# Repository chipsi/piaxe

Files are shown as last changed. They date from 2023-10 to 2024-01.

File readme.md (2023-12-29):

This Raspberry Pi mining HAT is based on the [BitAxe Ultra 1.3](https://github.com/skot/bitaxe
) (with BM1366) design.

Update: Miner is running stable 🥳



Changes to BitAxe Ultra
=======================

- powered by 12V and
- added TVS diode and fuses
- revised buck switching regulator circuit
- revised heatsink
- removed like DAC (only fixed 1.2V on PiAxe), current measurement, fan PWM controller, additional testpoints
- smallest components have 0805 size for easier manual assembly
- LM75 compatible temperature sensor under the heatsink

Installation
=============

- add to `/boot/config.txt`:
```
dtoverlay=pwm
```

- enable `serial` and `I2C` via `raspi-config`

If you want to use Influx and Grafana you need docker too:

```bash
$ curl -sSL https://get.docker.com | sh
```

Python:
```bash
# install pip3
$ sudo apt install python3-pip

# install libraries
$ for lib in pyserial rpi_hardware_pwm smbus influxdb-client pytz; do pip3 install $lib; done

# install i2c-tools
$ sudo apt install i2c-tools
```

Mining Client
=============



Stratum Mining Client:<br>
https://github.com/shufps/piaxe-miner

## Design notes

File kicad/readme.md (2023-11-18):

Original Repository: https://github.com/skot/bitaxe

This is a variant (Bitaxe ultra 1.3 with BM1366) for Raspberry Pi.

Please don't use it for production yet, the previous version had some issues and the 1.2 version is not yet tested.



Differences:

- powered by 12V and
- added some protection like TVS diode and fuses
- revised buck switching regulator circuit
- revised heatsink
- removed every additional features like DAC, current- and temperature measurement, temperature controlled fan PWM controller, additional testpoints
- replaced level shifter IC with smaller one-channel SC70-5 types
- smallest components have 0805 size for easier manual assembly

Installation:

- add to `/boot/config.txt`:
```
dtoverlay=pwm
```

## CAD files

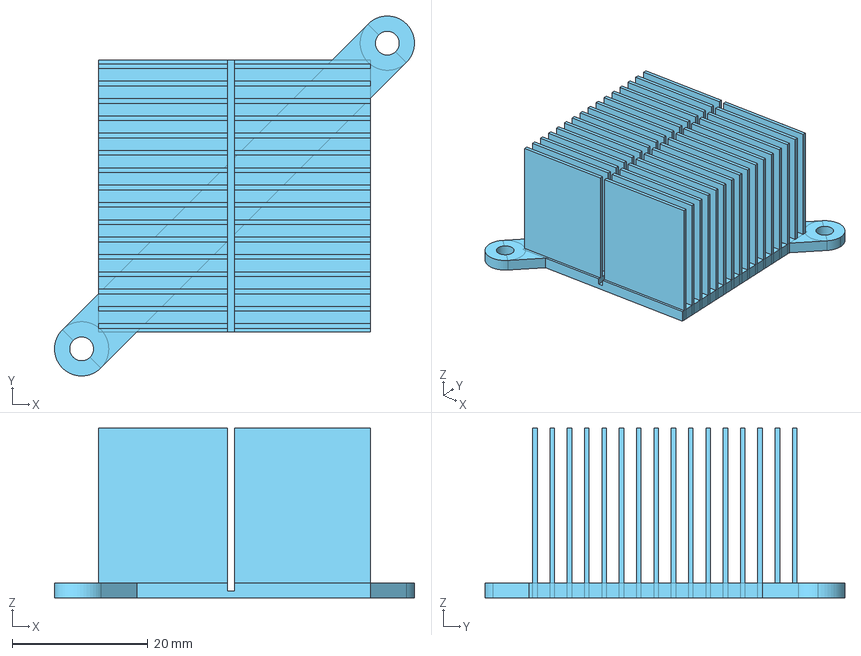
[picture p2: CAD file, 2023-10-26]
3d/heatsink-40x40-2.step
53.0 x 53.0 x 25.0 mm

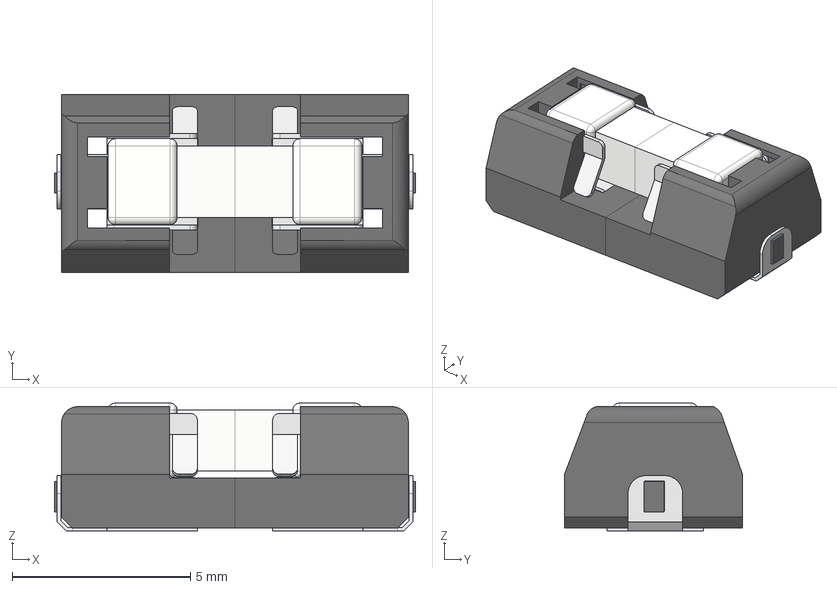
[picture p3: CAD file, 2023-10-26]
3d/Littelfuse 0154.500DRT without value_black v2.step
10.1 x 5.00 x 3.59 mm
Komponente1
Komponente2
Komponente3
Komponente4

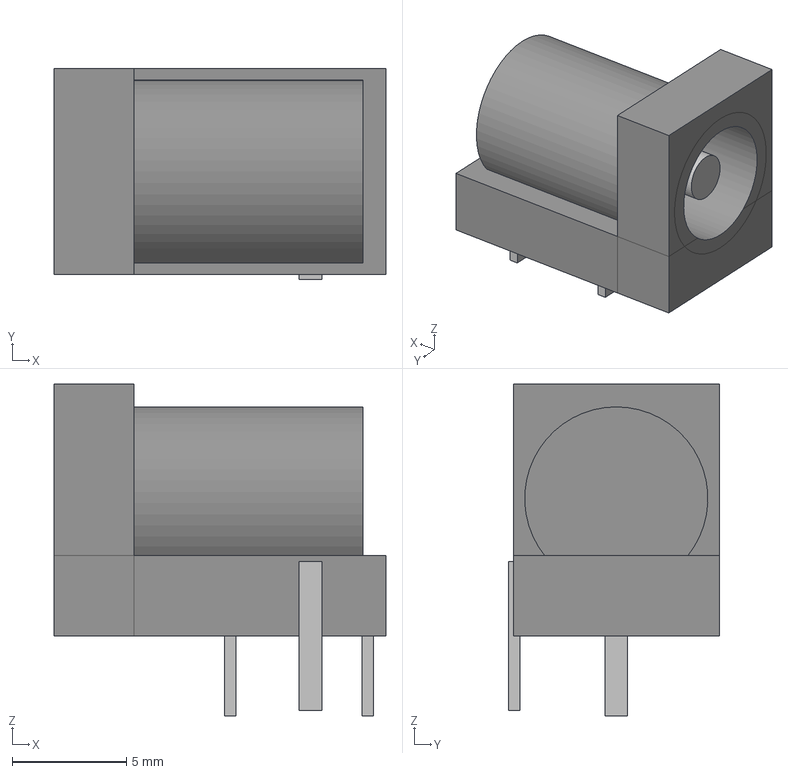
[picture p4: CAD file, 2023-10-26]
3d/barrel-jack.step
14.5 x 9.20 x 14.5 mm

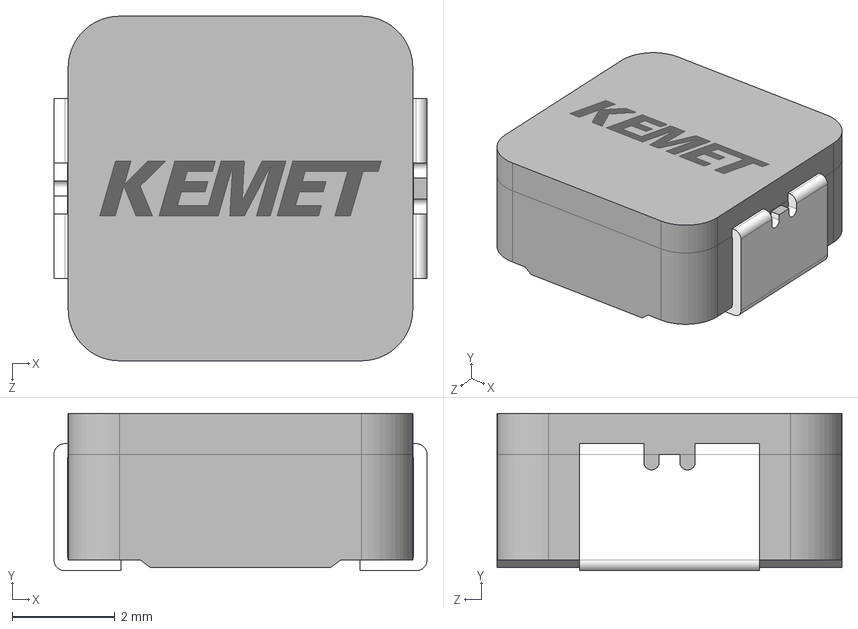
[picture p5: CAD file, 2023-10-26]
3d/MPXV1D0630LR33.step
7.25 x 3.06 x 6.70 mm

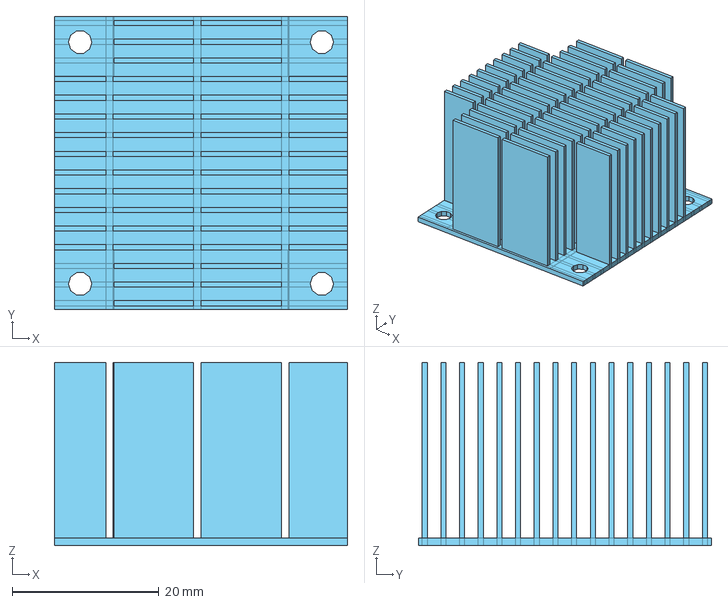
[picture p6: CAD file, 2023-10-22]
3d/heatsink-40x40.step
40.0 x 40.0 x 25.0 mm

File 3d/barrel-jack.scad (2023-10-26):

$fn=50;

color("#404040") difference() {
    union() {
        translate([0, 0, 6]) rotate([0,90,0]) cylinder(d=8, h=13.5);
        translate([0, -4.5, 0]) cube([3.5, 9, 11]);
        translate([0, -4.5, 0]) cube([14.5, 9, 3.5]);
    }
    translate([-1, 0, 6]) rotate([0,90,0]) cylinder(d=6.4, h=14);
}

color("gray") translate([1, 0, 6]) rotate([0,90,0]) cylinder(d=2.5, h=12);

color("gray") {
//    translate([7.7, 0, -3.5]) cylinder(d=1, h=3.5);
//    translate([7.7 + 6, 0, -3.5]) cylinder(d=1, h=3.5);
//    translate([7.7 + 3, -4.7, -3.5]) cylinder(d=1, h=6.5);

    translate([7.7, 0, -3.5/2]) cube([0.5, 1, 3.5], center=true);
    translate([7.7 + 6, 0, -3.5/2]) cube([0.5, 1, 3.5], center=true);
    translate([7.7 + 3, -4.7, -6.5/2]) cube([1, 0.5, 6.5]);
    
    
    
}

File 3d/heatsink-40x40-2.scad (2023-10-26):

$fn=100;
a=8.1;
h=3.5;
color("#31aee1") difference() {
    union() {
        cube([40, 40, 2.2]);

        for (i=[0: 15]) {
            translate([0, 0.5+i*2.55, 0]) cube([40, 0.7, 25]);
        }
        translate([20, 20, 1.1]) rotate([0, 0, 45]) cube([71.6-8, 8, 2.2], center=true);
        translate([-2.5, -2.5, 1.1]) cylinder(d=8, h=2.2, center=true);
        translate([2.5+40, 2.5+40, 1.1]) cylinder(d=8, h=2.2, center=true);
    }
    translate([20-1, 0, 1]) cube([1, 40, 25]);
    translate([-2.5, -2.5, 1.0]) cylinder(d=3.5, h=2.5, center=true);
    translate([2.5+40, 2.5+40, 1.0]) cylinder(d=3.5, h=2.5, center=true);
}

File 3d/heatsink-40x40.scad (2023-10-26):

$fn=10;
a=8.1;
h=3.5;
color("#31aee1") difference() {
    union() {
        cube([40, 40, 1]);

        for (i=[0: 15]) {
            translate([0, 0.5+i*2.55, 0]) cube([40, 0.7, 25]);
        }
    }
    for (i=[0:3]) {
        tx = (i % 2) == 0 ? 0 : (40-a);
        ty = floor(i / 2) != 0 ? 0 : (40-a);
        translate([tx, ty, 1]) cube([a, a, 25]);
    }
    for (i=[0:3]) {
        tx = (i % 2) == 0 ? h : (40-h);
        ty = floor(i / 2) != 0 ? h : (40-h);
        translate([tx, ty, -1]) cylinder(d=3.2, h=10);
    }
    translate([20-1, 0, 1]) cube([1, 40, 25]);
    translate([20-1+12, 0, 1]) cube([1, 40, 25]);
    translate([20-1-12, 0, 1]) cube([1, 40, 25]);
}

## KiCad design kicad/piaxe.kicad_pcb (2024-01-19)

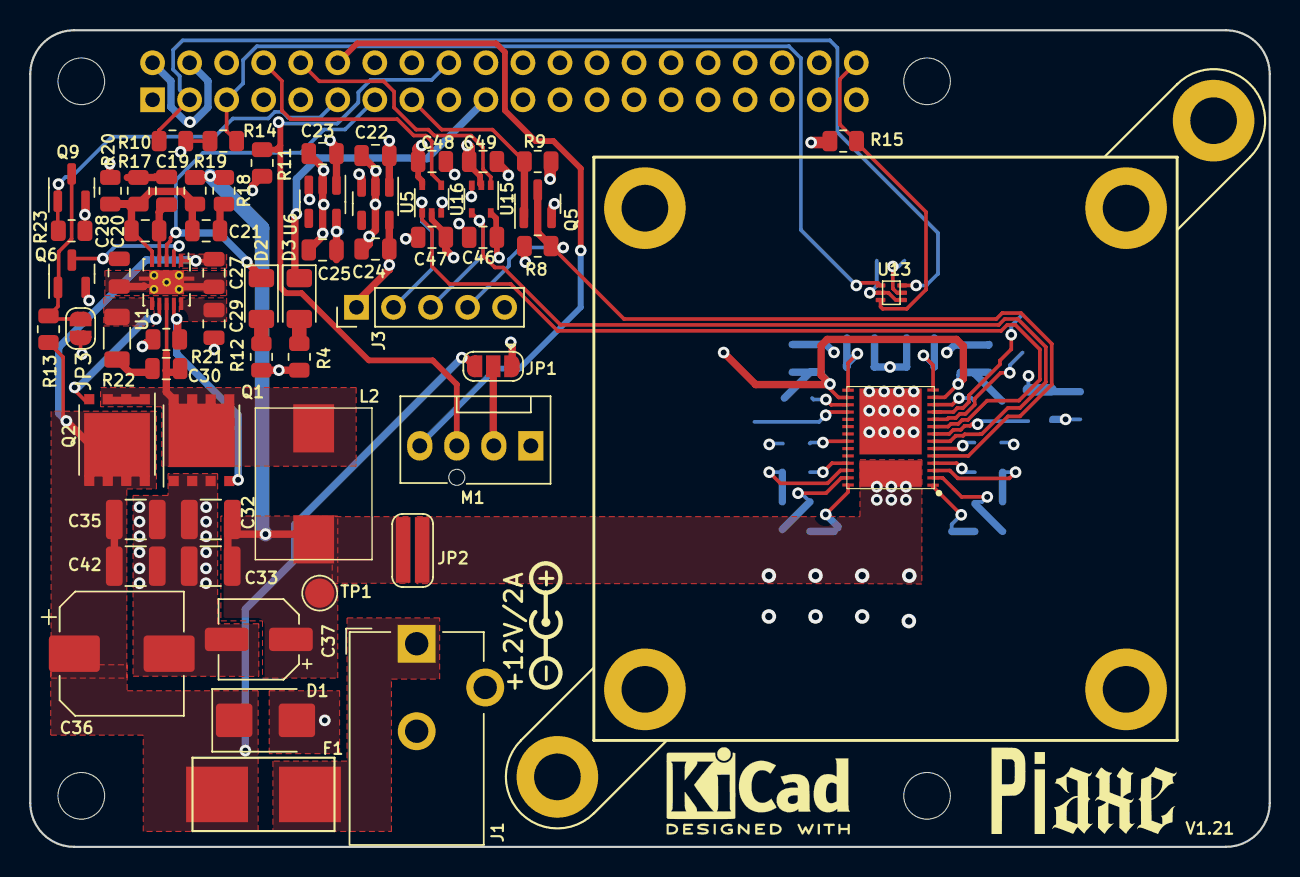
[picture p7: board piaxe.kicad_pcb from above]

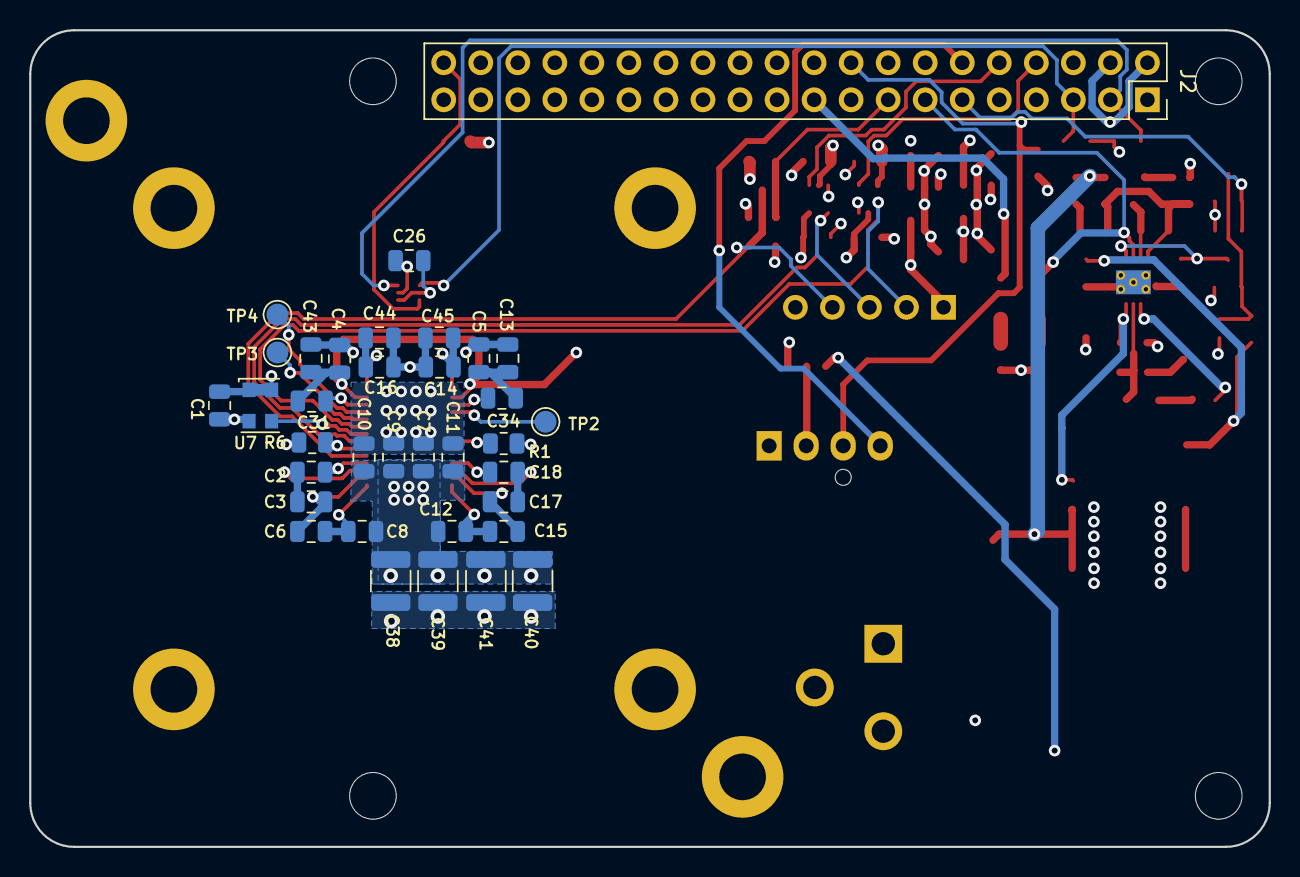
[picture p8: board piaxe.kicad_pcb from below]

Board: 4 copper layers, 85.0 x 56.0 mm, 103 parts (35 on the bottom side), 50 nets.

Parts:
C1, C7, C9, C13, C22, C23, C26, C30, C43, C44, C45, C46, C47, C48, C49: 100n; C_0805_2012Metric
C2, C3, C4, C5, C6, C8, C10, C11, C12, C14, C15, C16, C17, C18, C24, C25, C27, C31, C34: 1µ; C_0805_2012Metric
C19: 1.5n; C_0805_2012Metric
C20: 180p; C_0805_2012Metric
C21: 560p; C_0805_2012Metric
C28: 3.3n; C_0805_2012Metric
C29: 4.7µ/25V; C_0805_2012Metric
C32, C33, C40, C41: 47µ/6.3V; C_1210_3225Metric
C35: 1µ/25V; C_1210_3225Metric
C36: 330µ; CP_Elec_8x10
C37: 220µ; CP_Elec_5x5.8
C38, C39, C42: 10µ/25V; C_1210_3225Metric
D1: SMBJ12A; D_SMB
D2, D3: LED; LED_1206_3216Metric
F1: 2A; fuseholder_littlefuse_blok
H1, H2, H3, H4, H5, H6: MountingHole; MountingHole_3.2mm_M3_DIN965_Pad
J1: Barrel_Jack_Switch; BarrelJack_CUI_PJ-102AH_Horizontal
J2: Conn_02x20_Odd_Even; PinSocket_2x20_P2.54mm_Vertical
J3: Conn_01x05; PinHeader_1x05_P2.54mm_Vertical
JP1: SolderJumper_3_Open; SolderJumper-3_P1.3mm_Open_RoundedPad1.0x1.5mm
JP2: SolderJumper_2_Open; SolderJumper1.0x4.5
JP3: SolderJumper_2_Open; SolderJumper-2_P1.3mm_Open_RoundedPad1.0x1.5mm
L2: 170nH; IFLR-4031GC-01-8x10
M1: Fan_4pin; FanPinHeader_1x04_P2.54mm_Vertical
Q1, Q2: CSD17576Q5B; VSONP-8-1EP_5x6_P1.27mm
Q5, Q6, Q9: BSS138; SOT-23
R1, R6, R8, R9, R13, R15, R19, R20, R21, R23: 10k; R_0805_2012Metric
R4, R12: 560; R_0805_2012Metric
R10, R14: 1.5k; R_0805_2012Metric
R11: 2k2; R_0805_2012Metric
R17: 4.3k; R_0805_2012Metric
R18: 1.24k; R_0805_2012Metric
R22: 0; R_1206_3216Metric
TP1: +1V2; TestPoint_Pad_D2.0mm
TP2, TP3, TP4: TestPoint; TestPoint_Pad_D1.5mm
U1: TPS40305; VSON-10-1EP_3x3mm_P0.5mm_EP1.65x2.4mm_ThermalVias
U3: polarity
U5: MCP1824T-1802E; SOT-23-5
U6: MCP1824T-0802E; SOT-23-5
U7: 25MHz; Oscillator_SMD_EuroQuartz_XO32-4Pin_3.2x2.5mm
U13: TMP1075; TMP1075-DRL
U14: BM1366_mode1; BM1366
U15, U16: 2N7001TDCK; SOT-353_SC-70-5

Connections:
+0V8: C4.1, C5.1, C13.1, C25.1, C31.1, C34.2, C43.1, U6.5 (VOUT), U14.13 (VDDIO_08_0), U14.16 (VDDIO_08_1)
+1V2: C7.1, C8.2, C9.1, C10.1, C11.1, C12.1, C38.1, C39.1, C40.1, C41.1, JP2.2 (B), U14.29 (VDD)
+1V8: C1.1, C14.1, C16.1, C24.1, C44.1, C45.1, C46.1, C47.1, J3.1, R1.2, R8.2, U5.5 (VOUT), U7.1 (Standby), U7.4 (VDD), U14.14 (VDDIO_18_0), U14.15 (VDDIO_18_1), U15.5 (VCCA), U16.2 (VCCB)
+3V3: C26.1, C48.1, C49.1, J2.1, J2.17, R4.1, R9.2, R10.1, R11.1, R12.1, R14.1, R15.1, U13.5 (V+), U15.2 (VCCB), U16.5 (VCCA)
+5V: C22.1, C23.1, J2.2, J2.4, JP1.1 (A), U5.1 (VIN), U5.3 (EN), U6.1 (VIN), U6.3 (EN)
+12V: C27.1, C35.1, C36.1, C42.1, D1.1 (A1), F1.1, JP1.3 (B), Q2.3 (D), R13.2, U1.1 (VDD)
/BM1366/BI: R6.2, U14.6 (BI)
/BM1366/CI: J3.2, U14.9 (CI), U16.1 (B)
/BM1366/CLKI: U7.3 (Out), U14.8 (CLKI)
/BM1366/RO: J3.3, U14.7 (RO), U15.4 (A)
/BM1366/RST_N: J3.4, Q5.3 (D), R8.1, U14.5 (NRSTI)
/BM1366/TEMP_N: TP4.1, U14.11 (ADDR1)
/BM1366/TEMP_P: TP3.1, U14.10 (ADDR0)
/Pi/ALERT: J2.40, R15.2, U13.3 (ALERT)
/Pi/NRST: J2.15, Q5.1 (G), R9.1
/Pi/PGOOD: D2.1 (K), J2.13, U1.3 (PGOOD)
/Pi/PWM: J2.12, M1.4 (PWM)
/Pi/RXD: J2.10, U15.1 (B)
/Pi/SCL: J2.5, R14.2, U13.1 (SCL)
/Pi/SDA: J2.3, R10.2, U13.6 (SDA)
/Pi/SDN: J2.11, Q9.1 (G), R23.2
/Pi/TACHO: J2.18, M1.3 (Tacho), R11.2
/Pi/TXD: J2.8, U16.4 (A)
GND: C1.2, C2.1, C4.2, C5.2, C7.2, C9.2, C10.2, C11.2, C13.2, C14.2, C16.2, C18.2, C22.2, C23.2, C24.2, C25.2, C26.2, C27.2, C28.2, C29.2, C31.2, C32.2, C33.2, C34.1, C35.2, C36.2, C37.2, C38.2, C39.2, C40.2, C41.2, C42.2, C43.2, C44.2, C45.2, C46.2, C47.2, C48.2, C49.2, D1.2 (A2), J1.2, J1.3, J2.6, J2.9, J2.14, J2.20, J2.25, J2.30, J2.34, J2.39, J3.5, JP3.2 (B), M1.1 (-), Q1.1 (S), Q5.2 (S), Q6.2 (S), Q9.2 (S), R6.1, R20.1, R21.2, R23.1, U1.11 (GND), U5.2 (GND), U6.2 (GND), U7.2 (GND), U13.2 (GND), U13.4 (A0), U14.4 (VSS), U14.12 (PLL_VSS), U14.17 (VSS), U14.25 (VSS), U14.30 (GND), U15.3 (GND), U16.3 (GND)
unnamed: C19.2, R17.1
unnamed: C21.1, R18.2
unnamed: C30.1, R22.2
unnamed: D2.2 (A), R12.2
unnamed: D3.2 (A), R4.2
unnamed: D3.1 (K), J2.19
unnamed: F1.2, J1.1
unnamed: JP1.2 (C), M1.2 (+)
unnamed: C32.1, C33.1, C37.1, JP2.1 (A), L2.2, R18.1, R19.1, TP1.1
unnamed: JP3.1 (A), Q6.1 (G), Q9.3 (D), R13.1
unnamed: C30.2, L2.1, Q1.3 (D), Q2.1 (S), U1.8 (SW)
unnamed: Q1.2 (G), R21.1, U1.9 (LDRV/OC)
unnamed: Q2.2 (G), U1.7 (HDRV)
unnamed: C28.1, Q6.3 (D), U1.2 (EN/SS)
unnamed: R22.1, U1.6 (BOOT)
unnamed: C29.1, U1.10 (BP)
unnamed: C19.1, C20.1, U1.4 (COMP)
unnamed: C20.2, C21.2, R17.2, R19.2, R20.2, U1.5 (FB)
unnamed: TP2.1, U14.18 (PIN_MODE)
unnamed: R1.1, U14.22 (RI)
unnamed: C6.2, C8.1, U14.1 (VDD1_0)
unnamed: C12.2, C15.1, U14.28 (VDD1_1)
unnamed: C3.2, C6.1, U14.2 (VDD2_0)
unnamed: C15.2, C17.1, U14.27 (VDD2_1)
unnamed: C2.2, C3.1, U14.3 (VDD3_0)
unnamed: C17.2, C18.1, U14.26 (VDD3_1)

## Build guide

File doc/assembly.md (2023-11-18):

- Get a convection toaster oven. Nothing fancy, it just has a fan inside for more even heating. Never use this oven for food.
  - [BLACK+DECKER TO3250XSB 8-Slice Extra Wide Convection Countertop Toaster Oven, Includes Bake Pan, Broil Rack & Toasting Rack, Stainless Steel/Black](https://www.amazon.com/BLACK-DECKER-TO3250XSB-Convection-Countertop/dp/B00LU2I428)
- Get a thermocouple thermometer. Make sure the probe and probe jacket can go to ~300C
  - [Digital Thermocouple Temperature Thermometer, PEAKMETER PM6501 K Type LCD Thermometer Testing Tool Celsius and Fahrenheit](https://www.amazon.com/Thermocouple-Temperature-Thermometer-PEAKMETER-Fahrenheit/dp/B08L11MMFM)
- Use Sn63/Pb37 no-clean, leaded, solder paste. Keep it in the refrigerator so it's nice and cold before you stencil it. (obvs don't get it near your food). Wash your hands well after.
  - [Chip Quik SMD291AX50T3 Solder Paste in jar 50g (T3) Sn63/Pb37 no clean](https://www.amazon.com/gp/product/B07BH5LP5G)
- Take your time to get the paste stenciled right. Don't be afraid to wipe it off with IPA and try again. The paste stencils better when it's cold.
- Use tweezers to put all of the parts on the pasted board. I like the curved Aven Technik 7-SA Tweezers. I have also been known to wear a dorky magnifier headset.
  - [Aven 18072ARS 7-SA Style Artis Tweezer, Black with Yellow Print](https://www.amazon.com/Aven-18072ARS-Style-Tweezer-Yellow/dp/B01D4R1OXW)
  - [Headband Magnifier Hands Free Jeweler Loupe Head Mount Magnifying Headset Visor Double Optical Glass 4 Replaceable Lenses for Reading,Repair(1.5X,2.0X,2.5X,3.5X)](https://www.amazon.com/Headband-Magnifier-Jeweler-Magnifying-Replaceable/dp/B08RYVH7DL)
- Put the board(s) in the toaster oven. I usually put them right on the wire rack, which is in the metal tray.
- Put the thermocouple inside the toaster oven. Close the door on the thermocouple wire so that it holds the end right above the PCB, inside the oven.
- Turn the oven on convection bake, medium setting. The convection fan in the toaster oven helps keep the temperature even through out the inside of the oven.
- Once the temp (as read off the thermocouple thermometer) gets to 140C, turn down the oven heat and try and keep it at 140-150C for 2 minutes. Open the door a little if it's getting to hot. This is the "Soak" phase
- After two minutes, turn the heat to high
- Once the temp reaches 200C start a timer for 30 seconds. Keep the temp between 200 and 220C for this phase. Usually you don't need to do anything. This is the "Reflow" phase. You should see all of the paste melt.
- After 30 seconds, turn off the toaster oven. open the door.
- Let the boards cool for a bit in the oven with the door open.
- Once cool to touch, inspect the boards with a microscope for dry pads and/or bridges. Depending on how well you did with stenciling there may be a few, especially on QFP packages. QFNs sometimes too. Fix these up with paste flux, solder braid and your soldering iron.
- If you have parts on both sides of the board, it's fine to just repeat the steps on the second side. The surface tension of the solder almost always keeps the parts from falling off while they are getting reflowed upside down. When you reflow the second side, make a little stand out of metal to keep the bottom side parts off the wire rack in the toaster oven.

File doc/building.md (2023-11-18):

# Building PCBs

In order to get PCBs made, you usually need to provide them with the following files;

- Gerbers
- Drill Files

Additionally if you want to have a shop assemble the boards for you, you’ll also need to provide;

- Bill of Materials (BOM)
- Centroid file (XY)

### Generating Gerbers and Drill Files

Gerbers are a set of files in a standard format that allow a PCB manufacturer to build the PCB. Usually there is one gerber file for each layer of a PCB. A Gerber file can represent a wide variety of different layer types;

- Copper layer
- Silkscreen Layer
- Soldermask layer
- Board outline
- Drills (Okay, this is actually not a gerber, but your PCB house will definitely need it)

Any* PCB CAD software will allow you to generate gerbers. We use [KiCad](https://www.kicad.org) because it is open source, free, and *awesome*. Here is how to generate gerbers in KiCad v6;

1. Open up the design in KiCad and switch to the PCB board editor view (ie not the schematic). Some people call this pcbnew.
2. Choose File → Fabrication Outputs → Gerbers (.gbr)…
3. Pick the right options for what your PCB board house expects. Here is what I use;

Gerber Plot Window

Make sure you have these “Include Layers” checked;

- **F.Cu** → Front copper
- **In1.Cu** → Inner layer 1 Copper
- **In2.Cu** → Inner layer 2 Copper
- **B.Cu** → Back copper
- **F.Paste** → Front Paste. Note: this is used to make a solder paste stencil. This is optional. Many PCB houses will let you order stencils as a separate step. use these gerbers for ordering a stencil
- **B.Paste** → Back paste. see note above
- **F.Silkscreen** → Front Silkscreen. sometimes this is called the Legend
- **B.Silkscreen** → Back Silkscreen. sometimes this is called the Legend of Zelda
- **F.Mask** → Front soldermask
- **B.Mask** → Back soldermask
- **Edge.Cuts** → The board outline. This defines the shape the PCB is cut to.

1. Next you’ll want to generate the drill files. Click that button in the lower right corner of the “Plot” screen from above.
2. Generate the drill files according to your PCB house specs. Here are the options I use;

Drill Files Window

That’s it! Take all of those generated files and give them to your PCB house. If you’re ordering stencils (which you should!), pull out `-F_Paste.gbr` and `-B_Paste.gbr` and send those to the right place. Paste gerbers are not needed to manufacture a PCB.

### Generating PCBA Manufacturing files

- TBD

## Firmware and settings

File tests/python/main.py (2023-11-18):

import RPi.GPIO as GPIO
import serial
import time
import math
import logging
import struct
import hashlib

from rpi_hardware_pwm import HardwarePWM

from crc_package.crc_functions import crc5, crc16_false
from bm1366 import bm1366, utils

logging.basicConfig(level=logging.DEBUG)

# Setup GPIO
GPIO.setmode(GPIO.BOARD)  # Use Physical pin numbering

# Define the pin numbers:
SDN_PIN = 11  # SDN, output, initial high
PGOOD_PIN = 13  # PGOOD, input, floating
NRST_PIN = 15  # NRST, output, initial high
PWM_PIN = 12  # PWM output on Pin 12

# Initialize GPIO Pins
GPIO.setup(SDN_PIN, GPIO.OUT, initial=GPIO.HIGH)
GPIO.setup(PGOOD_PIN, GPIO.IN)  # Default is floating
GPIO.setup(NRST_PIN, GPIO.OUT, initial=GPIO.HIGH)

pwm = HardwarePWM(pwm_channel=0, hz=1000)
pwm.start(80) # full duty cycle

# Initialize serial communication
serial_port = serial.Serial(
    port="/dev/ttyS0",  # For GPIO serial communication use /dev/ttyS0
    baudrate=115200,    # Set baud rate to 115200
    bytesize=serial.EIGHTBITS,    # Number of data bits
    parity=serial.PARITY_NONE,    # No parity
    stopbits=serial.STOPBITS_ONE, # Number of stop bits
    timeout=1                     # Set a read timeout
)

def serial_tx_func(data, debug=False):
    serial_port.write(data)
    logging.debug("-> %s", bytearray(data).hex())
    time.sleep(0.01)

def serial_rx_func(size, timeout_ms, debug=False):
    serial_port.timeout = timeout_ms / 1000.0

    data = serial_port.read(size)
    bytes_read = len(data)

    logging.debug("serial_rx: %d", bytes_read)
    if bytes_read > 0:
        logging.debug("<- %s", data.hex())

    return data

def reset_func():
    GPIO.output(NRST_PIN, True)
    time.sleep(0.5)
    GPIO.output(NRST_PIN, False)
    time.sleep(0.5)

def is_power_good():
    return GPIO.input(PGOOD_PIN)


GPIO.output(SDN_PIN, False)


while (not is_power_good()):
    print("power not good ... waiting ...")
    time.sleep(5)


# set the hardware dependent functions for serial and reset
bm1366.ll_init(serial_tx_func, serial_rx_func, reset_func)

# init bm1366
bm1366.init(485)
init_response = bm1366.receive_work()

if init_response.nonce != 0x00006613:
    raise Exception("bm1366 not detected")

#bm1366.set_job_difficulty_mask(64)

def reverse_hex(hex_string):
    bytes = utils.hex2bin(hex_string)
    return bytearray(bytes[::-1]).hex()


work = bm1366.WorkRequest()


merkle_root_be = utils.swap_endianness_32bit(utils.hex2bin("768c54aa39f020353f6474b7b14e0add32e29cbd67b44326eb869f4557ce2f3d"))
prev_block_hash_be = utils.swap_endianness_32bit(utils.hex2bin("00000000000000000000332ccd3fb7c76ee315ba66b731bee66d49c8458bc095"))

work.create_work(
    0x28,
    0x00000000,
    0x187fffff, #nbits
    0x654de8ae,
    merkle_root_be,
    prev_block_hash_be,
    0x20000000
)
bm1366.send_work(work)

work.merkle_root = utils.hex2bin(reverse_hex("768c54aa39f020353f6474b7b14e0add32e29cbd67b44326eb869f4557ce2f3d"))
work.prev_block_hash = utils.hex2bin(reverse_hex("00000000000000000000332ccd3fb7c76ee315ba66b731bee66d49c8458bc095"))

time.sleep(0.5)


#cgminer nonce testing
# truediffone == 0x00000000FFFF0000000000000000000000000000000000000000000000000000
truediffone = 26959535291011309493156476344723991336010898738574164086137773096960.0


def verify_work(work, result):
    work.print()
    result.print()
    header = struct.pack('<I', work.version | (bm1366.reverse_uint16(result.version) << 13))
    header += work.prev_block_hash
    header += work.merkle_root
    header += struct.pack('<I', work.ntime)
    header += struct.pack('<I', work.nbits)
    header += struct.pack('<I', result.nonce)
    logging.debug("header: %s", bytearray(header).hex())

    # Hash the header twice using SHA-256.
    hash_buffer = hashlib.sha256(header).digest()
    hash_result = hashlib.sha256(hash_buffer).digest()
    logging.debug("result: %s", bytearray(hash_result).hex())
    #d64 = truediffone
    #s64 = utils.le256todouble(hash_result)
    #ds = d64 / s64
    return hash_result #ds

if False:
    dummywork = bm1366.WorkRequest()
    dummywork.version = 838860800
    dummywork.prev_block_hash = utils.hex2bin(reverse_hex("00000000000000000000332ccd3fb7c76ee315ba66b731bee66d49c8458bc095"))
    dummywork.merkle_root = utils.hex2bin(reverse_hex("768c54aa39f020353f6474b7b14e0add32e29cbd67b44326eb869f4557ce2f3d"))
    dummywork.ntime = 1699604654
    dummywork.nbits = 386171284


    dummyresult = bm1366.AsicResult()
    dummyresult.nonce = 3420097076
    dummyresult.version = 0

    verify_work(dummywork, dummyresult)

while True:
    result = bm1366.receive_work()
    # we assume we have some work done
    if result and result.nonce and result.nonce not in [0x0, 0x6613]:
        verify_work(work, result)


serial_port.close()  # Close the serial port

#pwm.stop()

# shutdown power supply
GPIO.output(SDN_PIN, True)

GPIO.cleanup()  # Reset the state of the GPIO pins

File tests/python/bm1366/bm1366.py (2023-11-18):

# python port from https://github.com/skot/ESP-Miner

import struct
import serial

import time
import math
import logging
import json
from crc_package.crc_functions import crc5, crc16_false
from bm1366 import utils

TYPE_JOB = 0x20
TYPE_CMD = 0x40

JOB_PACKET = 0
CMD_PACKET = 1

GROUP_SINGLE = 0x00
GROUP_ALL = 0x10

CMD_JOB = 0x01

CMD_SETADDRESS = 0x00
CMD_WRITE = 0x01
CMD_READ = 0x02
CMD_INACTIVE = 0x03

RESPONSE_CMD = 0x00
RESPONSE_JOB = 0x80

SLEEP_TIME = 20
FREQ_MULT = 25.0

CLOCK_ORDER_CONTROL_0 = 0x80
CLOCK_ORDER_CONTROL_1 = 0x84
ORDERED_CLOCK_ENABLE = 0x20
CORE_REGISTER_CONTROL = 0x3C
PLL3_PARAMETER = 0x68
FAST_UART_CONFIGURATION = 0x28
TICKET_MASK = 0x14
MISC_CONTROL = 0x18

serial_tx_func = None
serial_rx_func = None
reset_func = None

class AsicResult:
    # Define the struct format corresponding to the C structure.
    # < for little-endian, B for uint8_t, I for uint32_t, H for uint16_t
    _struct_format = '<2BIBBHB'

    def __init__(self):
        self.preamble = [0x00, 0x00]
        self.nonce = 0
        self.midstate_num = 0
        self.job_id = 0
        self.version = 0
        self.crc = 0

    @classmethod
    def from_bytes(cls, data):
        # Unpack the data using the struct format.
        unpacked_data = struct.unpack(cls._struct_format, data)

        # Create an instance of the AsicResult class.
        result = cls()

        # Assign the unpacked data to the class fields.
        result.preamble = list(unpacked_data[0:2])
        result.nonce = unpacked_data[2]
        result.midstate_num = unpacked_data[3]
        result.job_id = unpacked_data[4]
        result.version = unpacked_data[5]
        result.crc = unpacked_data[6]

        return result

    def print(self):
        print("AsicResult:")
        print(f"  preamble:        {self.preamble}")
        print(f"  nonce:           {self.nonce:08x}")
        print(f"  midstate_num:    {self.midstate_num}")
        print(f"  job_id:          {self.job_id:02x}")
        print(f"  version:         {self.version:04x}")
        print(f"  crc:             {self.crc:02x}")

class WorkRequest:
    def __init__(self):
        self.time = None
        self.id  = int(0)
        self.starting_nonce = int(0)
        self.nbits = int(0)
        self.ntime = int(0)
        self.merkle_root = bytearray([])
        self.prev_block_hash = bytearray([])
        self.version = int(0)

    def create_work(self, id, starting_nonce, nbits, ntime, merkle_root, prev_block_hash, version):
        self.time = time.time()
        self.id = id
        self.starting_nonce = starting_nonce
        self.nbits = nbits
        self.ntime = ntime
        self.merkle_root = merkle_root
        self.prev_block_hash = prev_block_hash
        self.version = version

    def print(self):
        print("WorkRequest:")
        print(f"  id:              {self.id:02x}")
        print(f"  starting_nonce:  {self.starting_nonce:08x}")
        print(f"  nbits:           {self.nbits:08x}")
        print(f"  ntime:           {self.ntime:08x}")
        print(f"  merkle_root:     {self.merkle_root.hex()}")
        print(f"  prev_block_hash: {self.prev_block_hash.hex()}")
        print(f"  version:         {self.version:08x}")



class TaskResult:
    def __init__(self, job_id, nonce, rolled_version):
        self.job_id = job_id
        self.nonce = nonce
        self.rolled_version = rolled_version


def ll_init(_serial_tx_func, _serial_rx_func, _reset_func):
    global serial_tx_func, serial_rx_func, reset_func
    serial_tx_func = _serial_tx_func
    serial_rx_func = _serial_rx_func
    reset_func = _reset_func


def send_BM1366(header, data, debug=False):
    packet_type = JOB_PACKET if header & TYPE_JOB else CMD_PACKET
    data_len = len(data)
    total_length = data_len + 6 if packet_type == JOB_PACKET else data_len + 5

    # Create a buffer
    buf = bytearray(total_length)

    # Add the preamble
    buf[0] = 0x55
    buf[1] = 0xAA

    # Add the header field
    buf[2] = header

    # Add the length field
    buf[3] = data_len + 4 if packet_type == JOB_PACKET else data_len + 3

    # Add the data
    buf[4:data_len+4] = data

    # Add the correct CRC type
    if packet_type == JOB_PACKET:
        crc16_total = crc16_false(buf[2:data_len+4])
        buf[4 + data_len] = (crc16_total >> 8) & 0xFF
        buf[5 + data_len] = crc16_total & 0xFF
    else:
        buf[4 + data_len] = crc5(buf[2:data_len+4])

    serial_tx_func(buf, debug)

def send_simple(data):
    serial_tx_func(data)

def send_chain_inactive():
    send_BM1366(TYPE_CMD | GROUP_ALL | CMD_INACTIVE, [0x00, 0x00])

def set_chip_address(chipAddr):
    send_BM1366(TYPE_CMD | GROUP_SINGLE | CMD_SETADDRESS, [chipAddr, 0x00])

def send_hash_frequency(target_freq):
    # default 200Mhz if it fails
    freqbuf = bytearray([0x00, 0x08, 0x40, 0xA0, 0x02, 0x41])  # freqbuf - pll0_parameter
    newf = 200.0

    fb_divider = 0
    post_divider1 = post_divider2 = ref_divider = 0
    min_difference = 10.0

    # Calculate dividers
    for refdiv_loop in range(2, 0, -1):
        if fb_divider != 0:
            break
        for postdiv1_loop in range(7, 0, -1):
            if fb_divider != 0:
                break
            for postdiv2_loop in range(1, postdiv1_loop):
                temp_fb_divider = round(postdiv1_loop * postdiv2_loop * target_freq * refdiv_loop / 25.0)

                if 144 <= temp_fb_divider <= 235:
                    temp_freq = 25.0 * temp_fb_divider / (refdiv_loop * postdiv2_loop * postdiv1_loop)
                    freq_diff = abs(target_freq - temp_freq)

                    if freq_diff < min_difference:
                        fb_divider = temp_fb_divider
                        post_divider1 = postdiv1_loop
                        post_divider2 = postdiv2_loop
                        ref_divider = refdiv_loop
                        min_difference = freq_diff
                        break

    if fb_divider == 0:
        logging.info("Finding dividers failed, using default value (200Mhz)")
    else:
        newf = 25.0 / ref_divider / fb_divider / (post_divider1 * post_divider2)
        logging.info(f"final refdiv: {ref_divider}, fbdiv: {fb_divider}, postdiv1: {post_divider1}, postdiv2: {post_divider2}, min diff value: {min_difference}")

        freqbuf[3] = fb_divider
        freqbuf[4] = ref_divider
        freqbuf[5] = ((post_divider1 - 1) & 0xf) << 4 | (post_divider2 - 1) & 0xf

        if fb_divider * 25 / ref_divider >= 2400:
            freqbuf[2] = 0x50

    # Send the frequency buffer
    send_BM1366(TYPE_CMD | GROUP_ALL | CMD_WRITE, freqbuf, debug=True)

    # Log the result
    logging.info(f"Setting Frequency to {target_freq:.2f}MHz ({newf:.2f})")
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

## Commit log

2023-10-21 added bitaxe variant for rasperry pi
    [bitaxeUltra.kicad_pcb, bitaxeUltra.kicad_sch, bm1366.kicad_sch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]
2023-10-21 removed manufacturer files because layout is different now
    [bitaxeUltra BOM.xlsx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]
2023-10-21 added missing schematic
    [pi.kicad_sch]
2023-10-21 added back the two 1uF
    [bitaxeUltra.kicad_pcb, bm1366.kicad_sch]
2023-10-21 removed tantal and replaced with ceramic caps
    [bitaxeUltra.kicad_pcb, bm1366.kicad_sch]
2023-10-22 revised heat-sinking. Supports heatsinks with 40x40 size with holes 35x35, 32x32 and 33x33
    [bitaxeUltra.kicad_pcb, bitaxeUltra.kicad_sch, bm1366.kicad_sch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]
2023-10-22 added gerbers and bom
    [bitaxeUltra-B_Cu.gbl, bitaxeUltra-B_Mask.gbs, bitaxeUltra-B_Paste.gbp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]
2023-10-22 added 40x40 openscad and step model
    [heatsink-40x40.scad, heatsink-40x40.step]
2023-10-23 fixed zone-edgecut clearance, added 2nd gnd layer and stitched them together for copper balance
    [bitaxeUltra-B_Cu.gbl, bitaxeUltra-B_Mask.gbs, bitaxeUltra-B_Paste.gbp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]
2023-10-23 removed useless snubber
    [bitaxeUltra.kicad_pcb, bitaxeUltra.kicad_sch, power.kicad_sch]
2023-10-24 renamed project to piaxe
    [piaxe-B_Cu.gbl, piaxe-B_Mask.gbs, piaxe-B_Paste.gbp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]
2023-10-26 added new 3d models
    [Littelfuse 0154.500DRT without value_black v2.step, MPXV1D0630LR33.step, barrel-jack.scad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]
2023-11-06 fixed some order numbers, added initial python code for testing
    [bm1366.kicad_sch, pi.kicad_sch, piaxe.kicad_pcb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]
2023-11-18 restructured a bit
    [bm1366.kicad_sch, pi.kicad_sch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]
2023-11-18 fixed paths to 3d models
    [piaxe.kicad_pcb]
2023-11-29 added solderjumper to enable the buck without Pi, changed LED values to 560R
    [bm1366.kicad_sch, pi.kicad_sch, piaxe.kicad_pcb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]
2023-11-29 fixed heatsink order number, updated BOM
    [bm1366.kicad_sch, digikey.csv, piaxe.kicad_sch]
2023-12-01 fixed net labeling to 1.2V
    [bm1366.kicad_sch, piaxe.kicad_pcb, piaxe.kicad_sch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]
2023-12-29 fixed bom for 2nd mosfet on buck
    [digikey.csv, power.kicad_sch]
2024-01-19 switched pinheader on top to pinsocket on bottom
    [pi.kicad_sch, piaxe.kicad_pcb]
